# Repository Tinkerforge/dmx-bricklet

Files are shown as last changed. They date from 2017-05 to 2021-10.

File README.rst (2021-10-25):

DMX Bricklet
============

This repository contains the firmware source code and the hardware design
files. The documentation generator configs can be found at
https://github.com/Tinkerforge/generators

Repository Content
------------------

software/:
 * examples/: Examples for all supported languages
 * build/: Compiled files
 * src/: Source code of firmware
 * Makefile: Makefile to build project

hardware/:
 * Contains KiCad project files and additionally schematics as PDF

datasheets/:
 * Contains datasheets for sensors and complex ICs that are used

Hardware
--------

The hardware is designed with the open source EDA Suite KiCad
(http://www.kicad.org). Before you are able to open the files,
you have to install the Tinkerforge kicad-libraries
(https://github.com/Tinkerforge/kicad-libraries). You can either clone
them directly in hardware/ or clone them in a separate folder and
symlink them into hardware/
(ln -s kicad_path/kicad-libraries project_path/hardware). After that you
can open the .pro file in hardware/ with KiCad and from there view and
modify the schematics and the PCB layout.

Software
--------

If you want to do your own Brick/Bricklet firmware development we highly
recommend that you use our build environment setup script and read the
tutorial (https://www.tinkerforge.com/en/doc/Tutorials/Tutorial_Build_Environment/Tutorial.html).

To compile the C code we recommend you to install the newest GNU Arm Embedded
Toolchain (https://launchpad.net/gcc-arm-embedded/+download).
You also need to install bricklib2 (https://github.com/Tinkerforge/bricklib2).

You can either clone it directly in software/src/ or clone it in a
separate folder and symlink it into software/src/
(ln -s bricklib_path/bricklib2 project_path/software/src/). Finally make sure to
have CMake installed (http://www.cmake.org/cmake/resources/software.html).

After that you can build the firmware by invoking make in software/.
The firmware (.zbin) can then be found in software/build/ and uploaded
with brickv (click button "Flashing" on start screen).

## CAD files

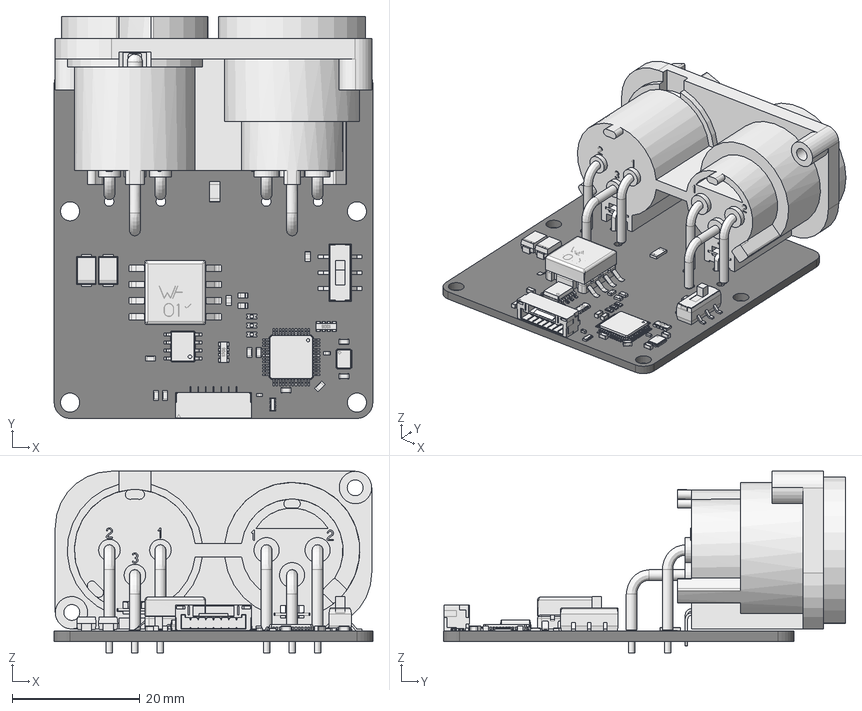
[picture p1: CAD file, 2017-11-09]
hardware/dmx.FCStd
50.0 x 63.1 x 28.5 mm
Pcb
R_4x0603_
lqfp48_7x7_p05_
R_4x0603_001
silde_switch_smd_
R_1206_
C_0603_
C_0603_001
C_0603_002
C_0603_003
C_0603_004
C_0603_005
C_0603_006
C_0603_007
C_0603_008
C_0402_
D_0603_red_
D_0603_blue_
DO-214AC_
DO-214AC_001
BrickletConn_7pin_
R_0603_
R_0603_001
R_0603_002
R_0603_003
R_0402_
soic_8_39x49_p127_
XLR_2x3_

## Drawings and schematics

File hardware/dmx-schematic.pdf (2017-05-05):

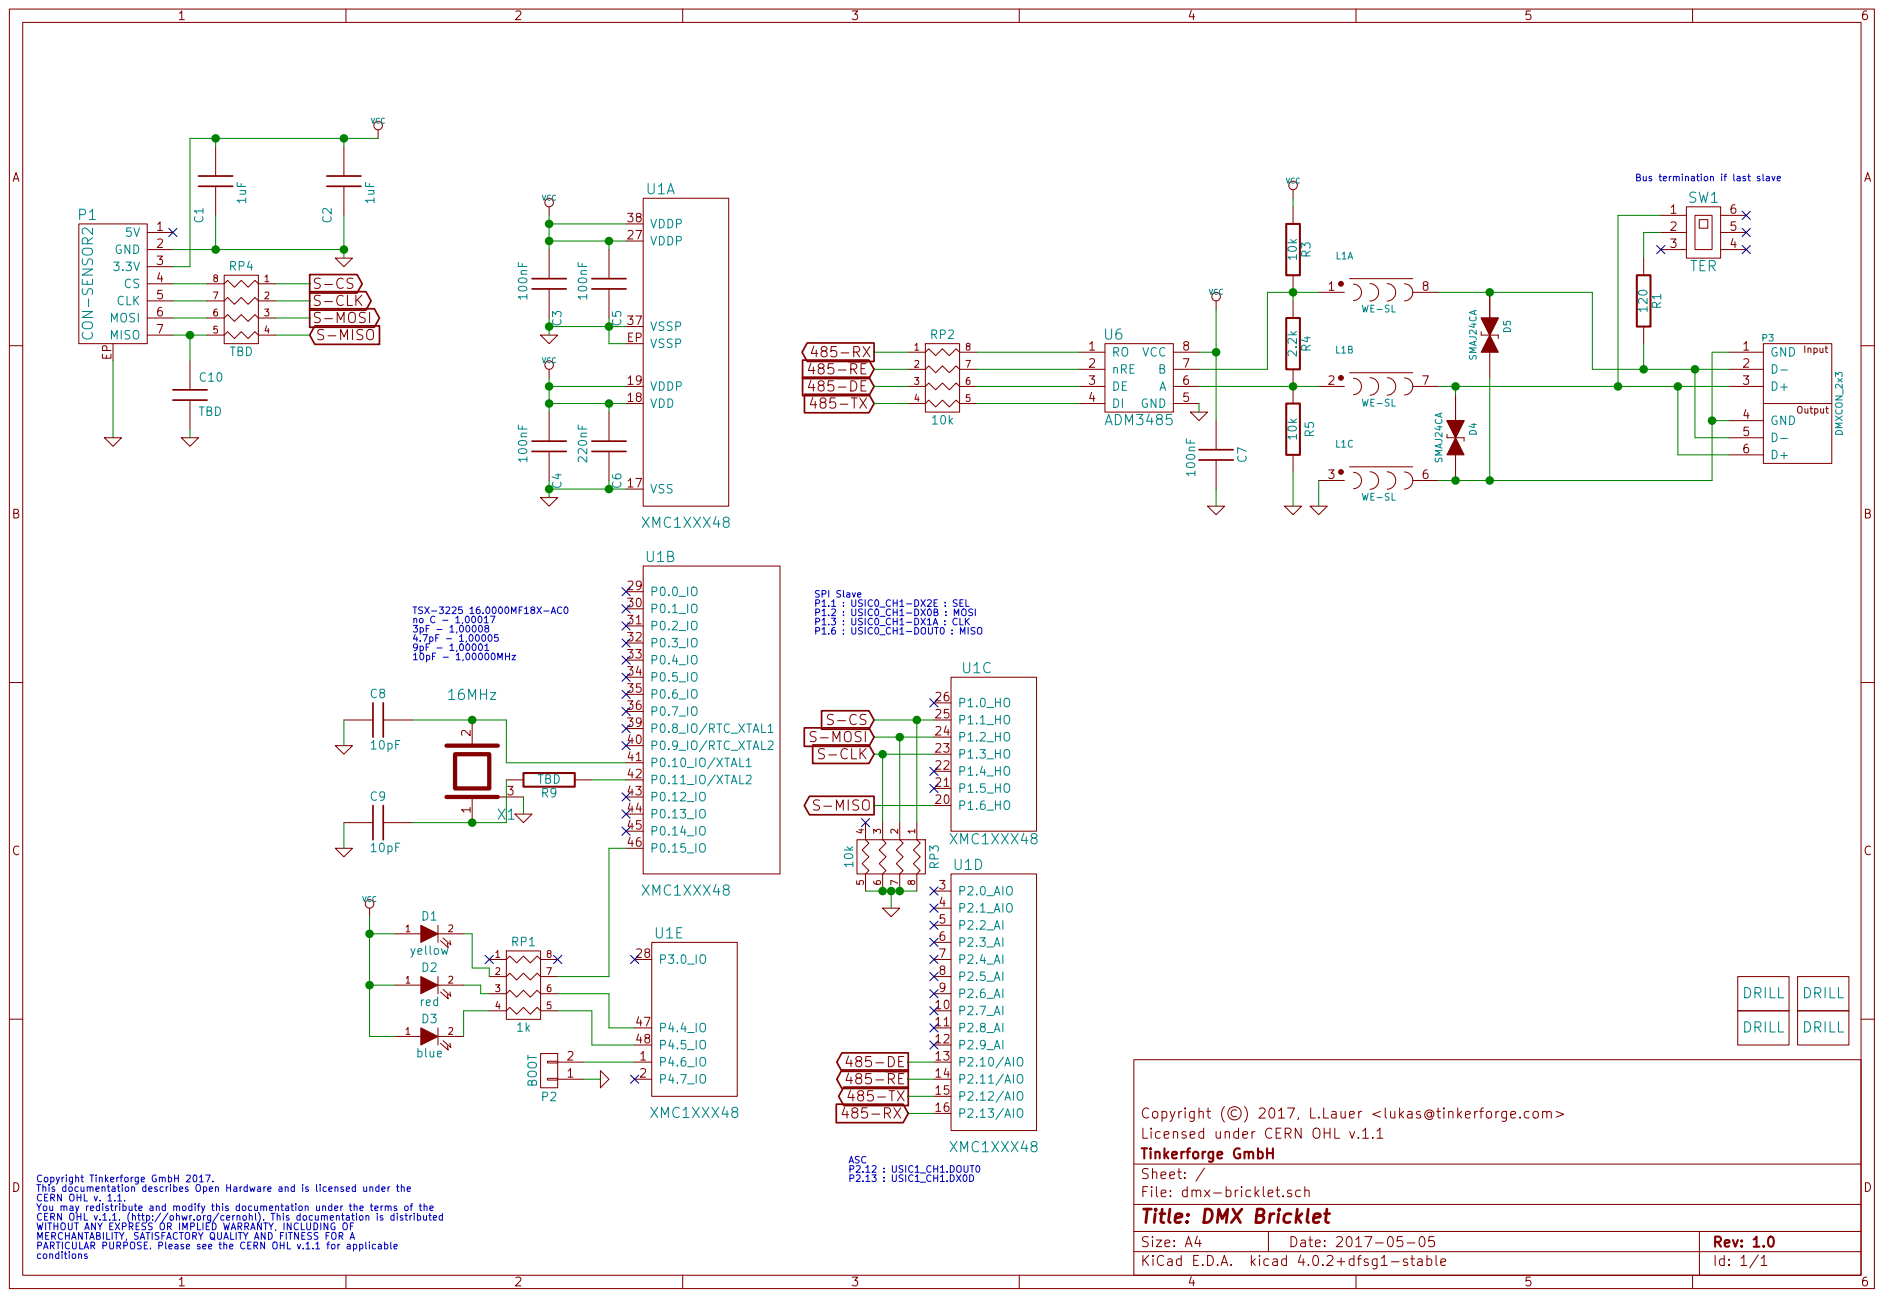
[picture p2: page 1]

Bus termination if last slave

SPI Slave P1.1 : USIC0_CH1-DX2E : SEL P1.2 : USIC0_CH1-DX0B : MOSI P1.3 : USIC0_CH1-DX1A : CLK

Licensed under CERN OHL v.1.1 Copyright (©) 2017, L.Lauer <lukas@tinkerforge.com>

Id: 1/1 Title: DMX Bricklet File: dmx-bricklet.sch Sheet: / Tinkerforge GmbH

Copyright Tinkerforge GmbH 2017. This documentation describes Open Hardware and is licensed under the CERN OHL v. 1.1. You may redistribute and modify this documentation under the terms of the CERN OHL v.1.1. (http://ohwr.org/cernohl). This documentation is distributed WITHOUT ANY EXPRESS OR IMPLIED WARRANTY, INCLUDING OF MERCHANTABILITY, SATISFACTORY QUALITY AND FITNESS FOR A

PARTICULAR PURPOSE. Please see the CERN OHL v.1.1 for applicable

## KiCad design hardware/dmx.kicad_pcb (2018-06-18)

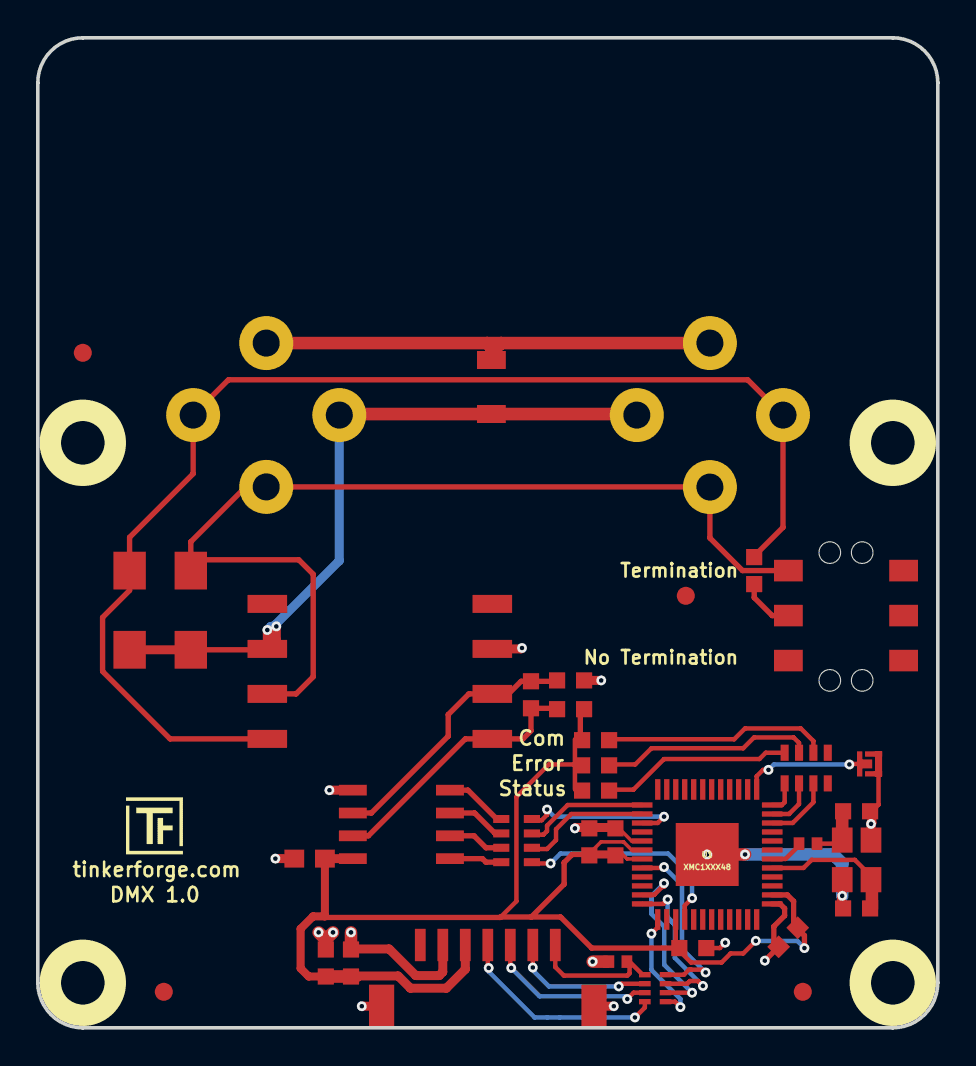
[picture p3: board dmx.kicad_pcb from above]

Board: 2 copper layers, 50.0 x 55.0 mm, 41 parts (0 on the bottom side), 35 nets.

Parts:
C1, C2: 1uF; C0603F
C3, C4, C5: 100nF; C0603F
C6: 220nF; C0603F
C7: 100nF; C0603E
C8, C9: 10pF; C0603F
C10: 220pF; C0402F
D1: yellow; D0603F
D2: red; D0603F
D3: blue; D0603F
D4, D5: SMAJ24CA; DO-214AC
Fiducial_Mark: VAL**; Fiducial_Mark
Fiducial_Mark#2, Fiducial_Mark#3, Fiducial_Mark#4: VAL**; Fiducial_Mark
L1: WE-SL
P1: CON-SENSOR2
P2: BOOT; SolderJumper
P3: DMXCON_2x3; DMX_IN_OUT_2x3POL
R1: 120; R0603F
R2: DNP; R1206
R3, R5: 10k; R0603F
R4: 2.2k; R0603F
R9: 0; R0402F
RP1: 1k; 0603X4
RP2: 10k; 0603X4
RP4: 82; 4X0402
SW1: TER; SLIDE_SWITCH
U1: XMC1XXX48; QFN48-EP2
U2, U3, U4, U5: DRILL; DRILL_NP
U6: ADM3485; SOIC8
VAL: CE_5mm
X1: 16MHz; CRYSTAL_3225

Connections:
485-DE: RP2.3, U1.13
485-RX: RP2.1, U1.28
485-TX: RP2.4, U1.15
485-~RE: RP2.2, U1.14
GND: C1.1, C2.1, C3.2, C4.2, C5.2, C6.2, C7.1, C8.2, C9.2, C10.2, L1.3, P1.2, P1.EP, P2.1, R5.2, U1.17, U1.37, U1.EP, U6.5, X1.3
unnamed: C8.1, U1.41, X1.2
unnamed: C9.1, R9.2, X1.1
unnamed: C10.1, P1.7, RP4.5
unnamed: D1.2, RP1.2
unnamed: D2.2, RP1.3
unnamed: D3.2, RP1.4
unnamed: D4.1, L1.7, P3.3, P3.6, SW1.1
unnamed: D4.2, D5.2, L1.6, P3.1, P3.4, R2.2
unnamed: D5.1, L1.8, P3.2, P3.5, R1.2
unnamed: L1.1, R3.2, R4.1, U6.7
unnamed: L1.2, R4.2, R5.1, U6.6
unnamed: P1.4, RP4.8
unnamed: P1.5, RP4.7
unnamed: P1.6, RP4.6
unnamed: P2.2, U1.1
unnamed: P3.7, P3.8, R2.1
unnamed: R1.1, SW1.2
unnamed: R9.1, U1.42
unnamed: RP1.5, U1.48
unnamed: RP1.6, U1.47
unnamed: RP1.7, U1.46
unnamed: RP2.5, U6.4
unnamed: RP2.6, U6.3
unnamed: RP2.7, U6.2
unnamed: RP2.8, U6.1
S-CLK: RP4.2, U1.23
S-CS: RP4.1, U1.25
S-MISO: RP4.4, U1.20
S-MOSI: RP4.3, U1.24
VCC: C1.2, C2.2, C3.1, C4.1, C5.1, C6.1, C7.2, D1.1, D2.1, D3.1, P1.3, R3.1, U1.18, U1.19, U1.27, U1.38, U6.8

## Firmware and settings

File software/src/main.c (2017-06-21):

/* dmx-bricklet
 * Copyright (C) 2017 Olaf Lüke <olaf@tinkerforge.com>
 *
 * main.c: Initialization for DMX Bricklet
 *
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
 * You should have received a copy of the GNU Lesser General Public
 * License along with this library; if not, write to the
 * Free Software Foundation, Inc., 59 Temple Place - Suite 330,
 * Boston, MA 02111-1307, USA.
 */

#include <stdio.h>
#include <stdbool.h>

#include "configs/config.h"

#include "bricklib2/bootloader/bootloader.h"
#include "bricklib2/hal/system_timer/system_timer.h"
#include "communication.h"
#include "dmx.h"

DMX dmx;

int main(void) {
	communication_init();
	dmx_init(&dmx);

	while(true) {
		bootloader_tick();
		communication_tick();
		dmx_tick(&dmx);
	}
}

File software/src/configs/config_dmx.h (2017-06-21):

/* dmx-bricklet
 * Copyright (C) 2017 Olaf Lüke <olaf@tinkerforge.com>
 *
 * config_dmx.h: DMX specific configurations
 *
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
 * You should have received a copy of the GNU Lesser General Public
 * License along with this library; if not, write to the
 * Free Software Foundation, Inc., 59 Temple Place - Suite 330,
 * Boston, MA 02111-1307, USA.
 */

#ifndef CONFIG_DMX_H
#define CONFIG_DMX_H

#include "xmc_common.h"

#define DMX_LED_RED_PIN         P4_4
#define DMX_LED_YELLOW_PIN      P0_15

#define DMX_USIC_CHANNEL        USIC1_CH1
#define DMX_USIC                XMC_UART1_CH1

#define DMX_RX_PIN              P3_0
#define DMX_RX_INPUT            XMC_USIC_CH_INPUT_DX0
#define DMX_RX_SOURCE           0b100 // DX0E

#define DMX_TX_PIN              P2_12
#define DMX_TX_PIN_AF           (XMC_GPIO_MODE_OUTPUT_PUSH_PULL_ALT7 | P2_12_AF_U1C1_DOUT0)

#define DMX_NRXE_PIN            P2_11
#define DMX_TXE_PIN             P2_10

#define DMX_NRXE_AND_TXE_PORT   XMC_GPIO_PORT2
#define DMX_NRXE_PIN_NUM        11
#define DMX_TXE_PIN_NUM         10

#define DMX_TIMER_CCU4          CCU41
#define DMX_TIMER_CCU4_SLICE    CCU41_CC41

#define DMX_SERVICE_REQUEST_RX  2  // receive
#define DMX_SERVICE_REQUEST_TX  3  // transfer
#define DMX_SERVICE_REQUEST_TFF 4  // transfer frame finished
#define DMX_SERVICE_REQUEST_RXA 5  // alternate receive (parity error)

// Make sure that the priorities are as follows
// RX > TX = TFF
// TFF should never displace TX. TFF is unnecessary if we are in TX IRQ
// TX should never displace TFF. This would be a race condition
// RX interrupt will never be issued if TXE is set. If we are receiving a message,
// TX should never interrupt RX (we would lose data in this case)
// For full-duplex there is no TFF and RX should be higher priority then TX
#define DMX_IRQ_RX              11
#define DMX_IRQ_RX_PRIORITY     1
#define DMX_IRQCTRL_RX          XMC_SCU_IRQCTRL_USIC1_SR2_IRQ11

#define DMX_IRQ_TX              12
#define DMX_IRQ_TX_PRIORITY     1
#define DMX_IRQCTRL_TX          XMC_SCU_IRQCTRL_USIC1_SR3_IRQ12

#define DMX_IRQ_TFF             13
#define DMX_IRQ_TFF_PRIORITY    1
#define DMX_IRQCTRL_TFF         XMC_SCU_IRQCTRL_USIC1_SR4_IRQ13

#define DMX_IRQ_RXA             14
#define DMX_IRQ_RXA_PRIORITY    1
#define DMX_IRQCTRL_RXA         XMC_SCU_IRQCTRL_USIC1_SR5_IRQ14

#define DMX_IRQ_TIMER           21
#define DMX_IRQ_TIMER_PRIORITY  0
#define DMX_IRQCTRL_TIMER       XMC_SCU_IRQCTRL_CCU41_SR0_IRQ21

#endif

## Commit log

2017-02-15 Add schematic
    [dmx-bricklet.sch]
2017-02-16 Change transreciever IC to ADM3485 (half-duplex)
    [dmx-bricklet.sch]
2017-02-17 Add PCB layout
    [dmx-bricklet.sch]
2017-02-17 Remove PTC1
    [dmx-bricklet.kicad_pcb, dmx-bricklet.sch]
2017-02-20 Add WEEE and CE logos
    [dmx-bricklet.kicad_pcb]
2017-03-01 Fix CE logo
    [dmx-bricklet.kicad_pcb]
2017-05-05 Change filtering to R/C circuit
    [dmx-bricklet.kicad_pcb, dmx-bricklet.sch]
2017-05-05 Add schematic PDF
2017-05-05 Remove RP3
    [dmx-bricklet.kicad_pcb, dmx-bricklet.sch]
2017-06-09 Add initial stub firmware implementation
    [cmake_config_custom.txt]
2017-06-20 change rx pin connection to p3.0
    [dmx-bricklet.kicad_pcb, dmx-bricklet.sch]
2017-06-20 drc check
    [dmx-bricklet.kicad_pcb]
2017-06-21 Add initial DMX Master and Slave implementation
    TODO: * Remove LED debug
    * Fix rare crash during mode change
    * Improve interrupt performance
    * Test with Master Brick under load
    [communication.c, communication.h, config_custom_bootloader.h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]
2017-06-21 Rename parity in framing error
    [communication.c, communication.h, dmx.c]
2017-06-21 Increase frame number each frame
2017-06-21 Remove prototype code (pin 2_13 is not connected in production board)
2017-08-10 hardware changes
    * increase board size to 60x50mm
    * add fiducials
    * fix all footprints with silkscreen layers
    * fix routing after moving connector
    [dmx-bricklet.kicad_pcb]
2017-08-10 add 3d model for slide switch
    [dmx-bricklet.kicad_pcb]
2017-08-11 add shielded dmx connector footprint, specify filter
    [dmx-bricklet.kicad_pcb, dmx-bricklet.sch]
2017-08-24 Fix edge cuts; specify R9 to 0Ohm
    [dmx-bricklet.kicad_pcb, dmx-bricklet.sch]
2017-11-06 Add final schematic
2017-11-09 Fix LED colors in 3d model
    [dmx-bricklet.kicad_pcb]
2017-11-09 Add 3d model (*.step & *.FCStd)
    [dmx-bricklet.FCStd]
2017-11-16 Remove bogus draw frame function
2017-11-16 add termination switch silkscreen description
    [dmx-bricklet.kicad_pcb]
2017-11-23 Unificate file names
    [dmx.FCStd, dmx.kicad_pcb, dmx.sch]
2018-02-20 Cleanup KiCad libraries config
    Ensure LibDir=kicad-libraries and LibName1=tinkerforge.
    Remove special library.
2018-06-18 Change capacitor footprint(s) to C0402F
    [dmx.kicad_pcb, dmx.sch]
2019-11-21 Add 4us wait-time between slots (some DMX slaves can not handle 0us wait time)
2020-09-02 uc: Add example driver note.
2021-10-25 Update KiCad link
    https://www.kicad.org/blog/2021/10/Avoid-links-to-former-kicad-domain/

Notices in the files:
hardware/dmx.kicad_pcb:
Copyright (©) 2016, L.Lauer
